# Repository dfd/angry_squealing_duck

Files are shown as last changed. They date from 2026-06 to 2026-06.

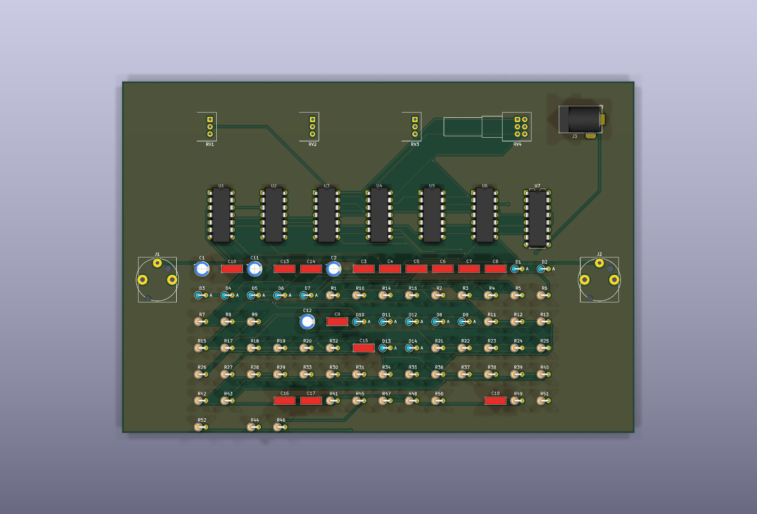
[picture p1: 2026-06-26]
kicad/duck_3d_top.png

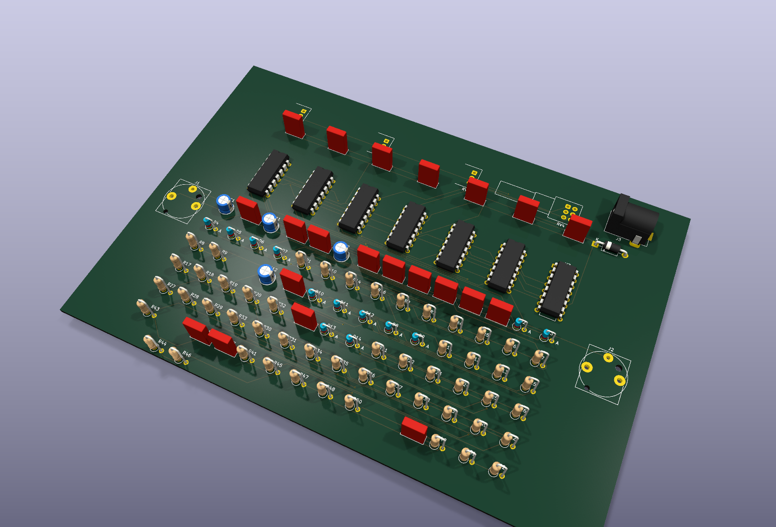
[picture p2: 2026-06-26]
kicad/duck_3d_persp.png

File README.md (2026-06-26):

# Angry Squealing Duck

A guitar pedal: a thick octave-fuzz feeding a dynamics-driven envelope band-pass
("Q-Tron") filter. Designed and voiced entirely in **ngspice**, validated against
real-part models, ready for KiCad.

**Controls (4 knobs + 2 footswitches):**
- **Volume** — output level
- **Anger** — fuzz amount / sustain (Big-Muff-style)
- **Squeal** — up-octave level: CCW = none, ~noon = "ring on top", CW = octave-dominant blast
- **Quack** — envelope band-pass intensity (ganged sweep depth + resonance Q)
- **Master** true-bypass footswitch, and a dedicated **Squeal (octave) footswitch**
  (kick the octave in/out, Hoof-Reaper style)

All knobs CCW = that effect off.

## Signal architecture

```
 IN ─► Input buffer ─► SPLIT ─┬─ AUDIO: Fuzz(Anger) ─┬─► BP envelope filter(Quack) ──┐
                              │                       └─► Octave-up(Squeal) ─► fixed HP┤─►[Volume]─► OUT
                              └─ CONTROL: Envelope follower (raw) ─► Iabc (cutoff) ─────┘
```

Key voicing decisions (each one earned the hard way — see `git log` / memory):
- **Octave AFTER the fuzz** (Octavia / Fender-Blender pattern): rectifying the distorted
  signal yields a prominent ring. Octave *before* the fuzz buried it ~30 dB under the
  fuzz's odd harmonics.
- **Body and octave on separate filter paths** ("hybrid" route): the fuzz body goes
  through the **band-pass** envelope filter (it quacks); the octave goes through a
  **fixed high-pass** (stays clear/bright instead of being swept under). A single shared
  filter ("mixed") muffled the octave.
- **Envelope tapped from the RAW split** (pre-fuzz) so the filter tracks picking dynamics
  — fuzz compresses dynamics away.

## Design choices

- Single **9 V** supply, **op-amp-buffered 4.5 V** virtual ground (`vref`) — a passive
  divider sags under the high-gain fuzz. Every stage input is AC-coupled.
- **Fuzz** = 3-stage cascaded **Big-Muff-style soft-clipper** with asymmetric stages for
  warmth (`fuzz_muff.cir`, default). A single-stage hard clipper (`fuzz.cir`, DOD-250
  family) is kept selectable via the `muff` param.
- **Octave** = op-amp **precision full-wave rectifier** (`fwr.cir`), no transformer.
  `octave_gen.cir` produces octave-only; Squeal level is **quadratic** so noon = ring,
  full = blast (`goct=8`, ~+9 dB octave-over-body, calibrated on real DI clips).
- **Envelope follower** = precision rectifier + **2-pole averaging** (not peak-detect,
  which hunted in a ~12 Hz limit cycle that re-triggered the filter on held notes).
- **Filter** = **LM13700 OTA state-variable** filter (`vcf.cir` behavioral / `vcf_real.cir`
  real). Has LP/BP/HP/mixed taps (Q-Tron-style mode); the hybrid route uses BP for the
  body. Quack maps to a **linear Q (0.7→3.5)** and an envelope-swept cutoff (gm = Iabc).
  gm control is ground-referenced to avoid a virtual-ground latch.
- **Behavioral-ideal first** to lock topology/voicing, then **real part models** for build
  accuracy (`opamp_real.sub` = TL072, `lm13700.sub` = OTA) — validated: voicing essentially
  unchanged on real silicon. See `memory` / `real-parts-and-build-notes`.

## Status

Design, voicing, real-part validation, **and a routed KiCad PCB are complete.**

| done | |
|---|---|
| ✅ | All blocks designed + integrated (input buffer → fuzz → octave → filter → volume) |
| ✅ | Voiced by ear on real guitar (MOTU M2), grid of Squeal×Anger×Quack rendered |
| ✅ | Real part models (TL072 + LM13700) — chain converges, voicing holds |
| ✅ | All-real buildable netlist (`pedal_build.cir`, no B-sources) — re-validated |
| ✅ | Quack sweep restored: V-to-I gain ×73 → body cutoff ~280 Hz→2.1 kHz, auditioned-good |
| ✅ | KiCad PCB: placed, auto-routed, gerbers exported |
| ✅ | **Tier-1 de-risk audit** (`kicad/AUDIT.md`): caught + fixed **10 reversed diodes**; added per-IC decoupling + Schottky protection + center-neg polarity; **DRC 0 unconnected / 0 violations** |

**Quack note:** the real envelope is tiny (~0.04 V peak), so the V-to-I needs high gain
(`Rdi`/`Rdj` = 1.5k, `Rdf`/`Rdk` = 110k → ×73) for the filter to sweep. Quack is most
audible at lower Squeal — at full Squeal the octave sits on top by design.

**Audit caught a board-killer:** `duck.py` (hand-translated) had 10/14 diodes reversed
(fuzz clippers + both rectifiers) — ERC + sim pass anyway since the SPICE is a separate,
correct source. Fixed to match SPICE; see `kicad/AUDIT.md`. **Not yet hardware-validated:**
real noise floor + the LM13700 filter's behavior (the `/50` attenuation hack, Iabc ceiling) —
confirm by breadboarding the filter + fuzz before fab (`kicad/breadboard/`).

## Layout

- `spice/lib/`    — models: `opamp.sub` (ideal), `opamp_real.sub` (TL072),
  `lm13700.sub` (OTA), `diode.mod` (1N4148), `supply.cir` (buffered vref)
- `spice/blocks/` — one `.subckt` per block: `input_buffer`, `fuzz`, `fuzz_muff`, `fwr`,
  `octave_rect`/`octave_gen`, `hpf`, `gmint`+`vcf`/`vcf_real`, `envfollow`,
  `duck`(mixed)/`duck_split`(hybrid/parallel), `pedal`
- `spice/tests/`  — per-block test benches
- `sim/`          — Python harness: `run.py`, `render.py`, `octave_balance.py`,
  `fft_report.py`, `spicelib.py`, `extract_sample.py`
- `audio/in/`     — committed DI samples; `audio/out/` — rendered WAVs (git-ignored)
- `raw_wavs/`     — large source recordings (git-ignored)
- `kicad/`        — the board, generated programmatically:
  - `duck.py` (SKiDL netlist generator) → `duck.net` (ERC-clean) + `BOM.md`
  - `build_pcb.py` (pcbnew: parse netlist → place → board) ; `finish_pcb.py` (values + GND pour)
  - `duck.kicad_pcb` (routed, DRC-clean) ; `gerbers/` + `duck.drl` + `duck-pos.csv` (fab-ready)
  - `duck_3d_top.png` / `duck_3d_persp.png` (3D renders; or open the `.kicad_pcb` in pcbnew → `Alt+3`)
  - `AUDIT.md` (netlist-translation audit + gap fixes) ; `BOM.md` ; `COST.md` (build-cost estimate)
  - `pedal_build.cir` in `spice/blocks/` is the all-real buildable schematic-of-record
- `kicad/breadboard/` — prototype-first docs (build it on a breadboard before the PCB):
  - `BUILD_GUIDE.md` (staged bring-up) + `CONNECTIONS.md` (per-stage wiring tables, net = row)
  - `gen_blocks.py` / `make_tables.py` (generators) ; `0*.png` drawn schematics (simple stages)
- `audio/out/build_grid/` + `build_grid_orig/` — full real-parts grids (Squeal×Anger×Quack ∈ {0,0.5,1})

## KiCad / PCB workflow

The board is generated entirely by script (no GUI), bridging two Pythons because
`pcbnew` is built for system Python 3.14 while the sim harness uses uv's 3.13:
```
# 1. netlist (uv / 3.13)
KICAD8_SYMBOL_DIR=/usr/share/kicad/symbols uv run kicad/duck.py     # -> duck.net (+ ERC)
# 2. place + board (system python 3.14, needs pcbnew)
/usr/bin/python3 kicad/build_pcb.py                                 # -> duck.kicad_pcb
# 3. route: export DSN, run freerouting (needs a display, e.g. :0), import SES
/usr/bin/python3 -c "import pcbnew,sys; b=pcbnew.LoadBoard('kicad/duck.kicad_pcb'); pcbnew.ExportSpecctraDSN(b,'/tmp/duck.dsn')"
DISPLAY=:0 java -jar freerouting.jar -de /tmp/duck.dsn -do /tmp/duck.ses -mp 14
/usr/bin/python3 -c "import pcbnew; b=pcbnew.LoadBoard('kicad/duck.kicad_pcb'); pcbnew.ImportSpecctraSES(b,'/tmp/duck.ses'); pcbnew.SaveBoard('kicad/duck.kicad_pcb',b)"
# 4. finishing pass (snap values + GND pour) + checks + fab outputs
/usr/bin/python3 kicad/finish_pcb.py
kicad-cli pcb drc kicad/duck.kicad_pcb
kicad-cli pcb export gerbers --output kicad/gerbers/ kicad/duck.kicad_pcb
```
Board: 2-layer, 175×120 mm (1590DD-class), 6× TL074 + 1× LM13700 + 14× 1N4148,
4 knobs (Volume / Anger / Squeal / Quack-dual-gang). No graphical schematic
(eeschema has no scripting API) — `pedal_build.cir` + `duck.py` are the design-of-record.

## Prototype it first (breadboard)

`kicad/breadboard/` holds **prototype-first** docs. Build + test the circuit on solderless
breadboards one stage at a time before committing to the PCB — see `BUILD_GUIDE.md` for the
staged bring-up order (supply → input → fuzz → octave → envelope → V-to-I → filter → output)
and `CONNECTIONS.md` for per-stage wiring tables (**each net = one breadboard row**; IC pins
annotated). Each stage uses its own op-amp IC (not the PCB's shared packing) so it tests
standalone. Regenerate with `gen_blocks.py` + `make_tables.py`. (SKiDL's schematic auto-router
only handles the simple stages, so the dense ones are table-only — better for breadboarding anyway.)

## Workflow

Run a block test bench:
```
uv run sim/run.py spice/tests/tb_input_buffer.cir
```
Render guitar through the pedal (→ `audio/out/`):
```
# the LOCKED, buildable design (= the PCB): real parts, no B-sources, V-to-I gain x73
uv run sim/render.py [wav] --build --squeal 1 --anger 0.8 --quack 0.6 [--subdir name]
# the behavioral routes (faster iteration / experiments):
uv run sim/render.py [wav] --route hybrid --squeal 1 --anger 0.8 --quack 0.6 [--real]
```
- **`--build`** = `pedal_build.cir`, the all-real buildable pedal that matches the PCB (use this).
- `--real` = TL072 + LM13700 models on the behavioral chain · `--route` = mixed|hybrid|parallel
- Scratch files are unique per render, so render a grid in parallel on many cores:
  `... | xargs -P 24 -I A sh -c 'uv run sim/render.py A'`
  (the committed `audio/out/build_grid/` + `build_grid_orig/` are the `--build` grids of
  Squeal×Anger×Quack ∈ {0, 0.5, 1.0} on both DI samples).

Measure octave-vs-body level on real clips (don't trust single-note benches — they
over-read the octave ~6 dB):
```
uv run sim/octave_balance.py --wav audio/in/di_sample.wav --squeal 1.0 --goct 8
```

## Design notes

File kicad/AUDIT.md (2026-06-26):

# Netlist audit + gap-fixes (Tier-1 de-risk)

Virtual pass before breadboarding/fab: cross-checked the hand-written `duck.py` netlist
against the validated SPICE (`spice/blocks/*`) + part datasheets, and closed the physical gaps
the simulation can't model. ERC only proves the copper matches `duck.py` — it can't catch a
wrong translation, so this was done by hand.

## 🔴 Bug found + fixed — 10 of 14 diodes were reversed

The biggest risk in any hand-translated netlist: diode orientation. ERC and simulation both
pass regardless (the SPICE blocks are a *separate*, correct source). Found:

| where | count | was | now |
|---|---|---|---|
| Fuzz clipper `dba`/`dbb` (the 2-diode side of each asymmetric soft-clipper), ×3 stages | 6 | reversed | matches `fuzz_muff.cir` (`Da1`/`Db1a`/`Db1b`) |
| Precision rectifier `d1`/`d2`, ×2 instances (octave + envelope) | 4 | reversed (even contradicted their own comments) | matches `fwr.cir` (`D1 a1o n1`, `D2 hw a1o`) |

`1N4148` symbol pinout is **pin 1 = K (cathode), pin 2 = A (anode)** — verified from the
library, not assumed. **Built as-was, this board would have had a broken octave + envelope
(no quack) and a wrong-sounding fuzz.** This alone justified the audit.

## ✅ Verified correct (no change needed)

- **TL074** section pinout — out/−/+ = (1,2,3)(7,6,5)(8,9,10)(14,13,12), V+ 4 / V− 11.
- **LM13700** — Iabc 1/16, +in 3/14, −in 4/13, out 5/12, V+ 11 / V− 6; non-inverting
  integrators match `vcf_build.cir`.
- All op-amp stage wiring (input buffer, 3 fuzz gain stages, both rectifiers, envelope,
  octave makeup, V-to-I diff amp ×73, SVF summer/inverter, output summer + buffers).
- **Pots** — Volume/Squeal (dividers), Anger (rheostat), **Quack dual-gang**
  (`R_Potentiometer_Dual_Separate`: 1-3 = sweep crossfade, 4-6 = filter-Q). All correct.
- **Jacks** (AudioJack2 T/S, Barrel_Jack), the Vref buffer + divider, and the unused
  LM13700 buffer/diode-bias pins (tied/NC).

## 🟢 Physical gaps closed

1. **Per-IC decoupling** — added **7× 0.1 µF** from V+ → GND, one at each IC, **placed
   beside the chip** on the board. Was missing entirely (only a 100 µF bulk + 47 µF Vref cap
   existed) — a real oscillation/noise risk on a high-gain 7-IC design that SPICE can't show.
2. **Reverse-protection diode** — 1N4148 → **1N5817 Schottky** (handles supply current, low
   drop), placed by the DC jack.
3. **DC polarity pinned to center-negative** (Boss/standard: center pin = GND, sleeve = +9 V).
   ⚠️ **Verify against your barrel jack's actual pinout** — the Schottky blocks damage if a
   reversed/center-positive supply is plugged in, but get the convention right for it to power on.

## Breadboard generator independently verified (second translation)

The breadboard docs (`kicad/breadboard/CONNECTIONS.md`, schematics) come from a *separate*
hand-written generator — `kicad/breadboard/gen_blocks.py` — not `duck.py`. It was audited
against the SPICE on its own:

- **All 14 diodes correct.** gen_blocks uses a clean `diode(part, anode, cathode)` helper
  (`part[2]=A, part[1]=K`); the fuzz clippers (`Da1/Db1a/Db1b`) and both rectifiers
  (`D1 a1o n1`, `D2 hw a1o`) match the SPICE in `CONNECTIONS.md`. **The `duck.py` diode bug
  did NOT exist here** — it was specific to duck.py's direct K/A pin assignment.
- TL072/TL074 section maps + power pins, the **LM13700** pinout (Iabc 1/16, +in 3/14, −in 4/13,
  out 5/12, V+ 11 / V− 6), and key values (V-to-I ×73, octave makeup, filter attenuator) all
  match the design.

So the audit covers **both** outputs: the PCB netlist (`duck.py`, diodes fixed) and the
breadboard docs (`gen_blocks.py`, already correct). No breadboard changes needed.

## Still untested by simulation (real-silicon, for the breadboard to confirm)
- Noise floor and real oscillation behavior (no noise analysis exists; layout-dependent).
- The LM13700 filter with the **/50 input attenuation** hack instead of the on-chip
  linearizing diodes (diode-bias pins left open) — distortion/headroom, and behavior near the
  ~1 mA Iabc ceiling at full sweep. These are exactly what the Tier-2 breadboard checks.

Bottom line: the **logic/translation bugs are now scrubbed out** (diodes) and the **known
physical gaps closed** (decoupling, power). What remains is genuine real-silicon behavior —
the stuff worth breadboarding the filter + fuzz for.

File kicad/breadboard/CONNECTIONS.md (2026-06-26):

# Angry Squealing Duck - breadboard connection tables

Each **net = one breadboard row**: put every listed pin in that row. IC pins are
annotated with their function. Build in numbered order (see BUILD_GUIDE.md).

## supply - Supply / 4.5 V Vref

**ICs:** U1 (TL072)  |  **Pots:** none

| net (breadboard row) | connect these pins |
|---|---|
| **GND** | C1.2, C2.2, R2.2, U1.4 (V- (GND)) |
| **NREF** | C2.1, R1.2, R2.1, U1.3 (IN1+) |
| **V9** | D1.2 (A) |
| **VCC** | C1.1, D1.1 (K (band)), R1.1, U1.8 (V+ (VCC)) |
| **VREF** | U1.1 (OUT1), U1.2 (IN1-) |

## input_buffer - Input buffer

**ICs:** U1 (TL072)  |  **Pots:** none

| net (breadboard row) | connect these pins |
|---|---|
| **GND** | U1.4 (V- (GND)) |
| **IN** | C1.1 |
| **NP** | C1.2, R1.1, U1.3 (IN1+) |
| **SIG** | U1.1 (OUT1), U1.2 (IN1-) |
| **VCC** | U1.8 (V+ (VCC)) |
| **VREF** | R1.2 |

## fuzz_anger - Fuzz (Anger) - 3-stage Muff

**ICs:** U1 (TL074)  |  **Pots:** RV1 (100k)

| net (breadboard row) | connect these pins |
|---|---|
| **FZ** | C7.1, R10.2 |
| **FZ1** | C2.2, C3.1, D1.1 (K (band)), D2.2 (A), R3.2, U1.1 (OUT1) |
| **FZ2** | C4.2, C5.1, D4.1 (K (band)), D5.2 (A), R6.2, U1.7 (OUT2) |
| **FZ3** | C6.2, D7.1 (K (band)), D8.2 (A), R10.1, R9.2, U1.8 (OUT3) |
| **GND** | U1.11 (V- (GND)) |
| **N$1** | C1.2, R1.1, R2.1 |
| **N$10** | C5.2, R7.1, R8.1 |
| **N$11** | C6.1, D7.2 (A), D9.1 (K (band)), R8.2, R9.1, U1.9 (IN3-) |
| **N$13** | D8.1 (K (band)), D9.2 (A) |
| **N$2** | R2.2, RV1.1 |
| **N$3** | C2.1, D1.2 (A), D3.1 (K (band)), R3.1, RV1.2, RV1.3, U1.2 (IN1-) |
| **N$5** | D2.1 (K (band)), D3.2 (A) |
| **N$6** | C3.2, R4.1, R5.1 |
| **N$7** | C4.1, D4.2 (A), D6.1 (K (band)), R5.2, R6.1, U1.6 (IN2-) |
| **N$9** | D5.1 (K (band)), D6.2 (A) |
| **SIG** | C1.1 |
| **VCC** | U1.4 (V+ (VCC)) |
| **VREF** | C7.2, R1.2, R4.2, R7.2, U1.10 (IN3+), U1.3 (IN1+), U1.5 (IN2+) |

## octave_squeal - Octave (Squeal)

**ICs:** U1 (TL074)  |  **Pots:** RV1 (100k)

| net (breadboard row) | connect these pins |
|---|---|
| **FZ** | C1.1 |
| **GND** | U1.11 (V- (GND)) |
| **N$1** | C1.2, R1.1, R3.1 |
| **N$10** | R8.2, R9.1, U1.9 (IN3-) |
| **N$11** | C4.1, RV1.2 |
| **N$12** | C4.2, R10.1, U1.12 (IN4+) |
| **N$2** | R5.2, R6.1, U1.7 (OUT2) |
| **N$3** | D1.1 (K (band)), R1.2, R2.1, U1.2 (IN1-) |
| **N$4** | R3.2, R4.2, R5.1, U1.6 (IN2-) |
| **N$5** | D2.2 (A), R2.2, R4.1 |
| **N$6** | D1.2 (A), D2.1 (K (band)), U1.1 (OUT1) |
| **N$7** | C2.1, C3.1, R6.2 |
| **N$8** | C3.2, R7.1, U1.10 (IN3+) |
| **N$9** | R8.1, RV1.1, U1.8 (OUT3) |
| **OCTF** | U1.13 (IN4-), U1.14 (OUT4) |
| **VCC** | U1.4 (V+ (VCC)) |
| **VREF** | C2.2, R10.2, R7.2, R9.2, RV1.3, U1.3 (IN1+), U1.5 (IN2+) |

## envelope - Envelope follower

**ICs:** U1 (TL074)  |  **Pots:** none

| net (breadboard row) | connect these pins |
|---|---|
| **CV** | U1.8 (OUT3), U1.9 (IN3-) |
| **GND** | U1.11 (V- (GND)) |
| **N$1** | R5.2, R6.1, U1.7 (OUT2) |
| **N$2** | D1.1 (K (band)), R1.2, R2.1, U1.2 (IN1-) |
| **N$3** | R3.2, R4.2, R5.1, U1.6 (IN2-) |
| **N$4** | D2.2 (A), R2.2, R4.1 |
| **N$5** | D1.2 (A), D2.1 (K (band)), U1.1 (OUT1) |
| **N$6** | C1.1, R6.2, R7.1 |
| **N$7** | C2.1, R7.2, U1.10 (IN3+) |
| **SIG** | R1.1, R3.1 |
| **VCC** | U1.4 (V+ (VCC)) |
| **VREF** | C1.2, C2.2, U1.3 (IN1+), U1.5 (IN2+) |

## quack_vtoi - Quack control (envelope -> V-to-I)

**ICs:** U1 (TL074)  |  **Pots:** RV1 (100k)

| net (breadboard row) | connect these pins |
|---|---|
| **CV** | R5.1 |
| **ECTL** | R4.2, RV1.3, U1.7 (OUT2) |
| **GND** | R2.2, U1.11 (V- (GND)) |
| **N$1** | R1.2, R2.1, U1.3 (IN1+) |
| **N$2** | R3.2, R4.1, U1.6 (IN2-) |
| **N$3** | R5.2, R6.1, U1.5 (IN2+) |
| **N$4** | RV1.2, U1.10 (IN3+) |
| **VBIAS** | U1.8 (OUT3), U1.9 (IN3-) |
| **VCC** | R1.1, U1.4 (V+ (VCC)) |
| **VOFF** | R6.2, RV1.1, U1.1 (OUT1), U1.2 (IN1-) |
| **VREF** | R3.1 |

## filter_lm13700 - LM13700 band-pass filter

**ICs:** U1 (TL074), U2 (TL072), U3 (LM13700)  |  **Pots:** RV1 (100k)

| net (breadboard row) | connect these pins |
|---|---|
| **BODYF** | U2.1 (OUT1), U2.2 (IN1-) |
| **BP** | R12.1, R8.1, U1.8 (OUT3), U1.9 (IN3-), U2.3 (IN1+) |
| **FZ** | R3.1 |
| **GND** | U1.11 (V- (GND)), U2.4 (V- (GND)), U3.6 (V-) |
| **HP** | R10.1, R7.2, U1.7 (OUT2) |
| **LP** | R6.1, U1.13 (IN4-), U1.14 (OUT4) |
| **N$1** | R5.2, R6.2, R7.1, R9.2, RV1.2, RV1.3, U1.6 (IN2-) |
| **N$10** | C1.1, U1.10 (IN3+), U3.5 (OUT-A) |
| **N$11** | R12.2, R13.1, U3.14 (IN+B) |
| **N$12** | C2.1, U1.12 (IN4+), U3.12 (OUT-B) |
| **N$4** | R1.2, U3.1 (Iabc-A) |
| **N$5** | R2.2, U3.16 (Iabc-B) |
| **N$6** | R3.2, R4.1, U1.2 (IN1-) |
| **N$7** | R4.2, R5.1, U1.1 (OUT1) |
| **N$8** | R8.2, R9.1, RV1.1 |
| **N$9** | R10.2, R11.1, U3.3 (IN+A) |
| **VBIAS** | R1.1, R2.1 |
| **VCC** | U1.4 (V+ (VCC)), U2.8 (V+ (VCC)), U3.11 (V+) |
| **VREF** | C1.2, C2.2, R11.2, R13.2, U1.3 (IN1+), U1.5 (IN2+), U3.13 (IN-B), U3.4 (IN-A) |

## output - Output (mix + Volume)

**ICs:** U1 (TL072)  |  **Pots:** RV1 Volume (100k, audio taper)

| net (breadboard row) | connect these pins |
|---|---|
| **BODYF** | R1.1  (from filter stage BODYF) |
| **OCTF** | R2.1  (from octave stage OCTF) |
| **NSUM** | R1.2, R2.2, R3.1, U1.2 (IN1-) |
| **OPRE** | R3.2, U1.1 (OUT1), RV1.1 (end) |
| **VW** | RV1.2 (wiper), U1.5 (IN2+) |
| **OUT** | U1.7 (OUT2), U1.6 (IN2-)  -> output jack tip |
| **VREF** | U1.3 (IN1+), RV1.3 (end) |
| **VCC** | U1.8 (V+) |
| **GND** | U1.4 (V-) |

_R1=R2=R3 = 22k (mixer). Body + octave sum here, then Volume sets output level._

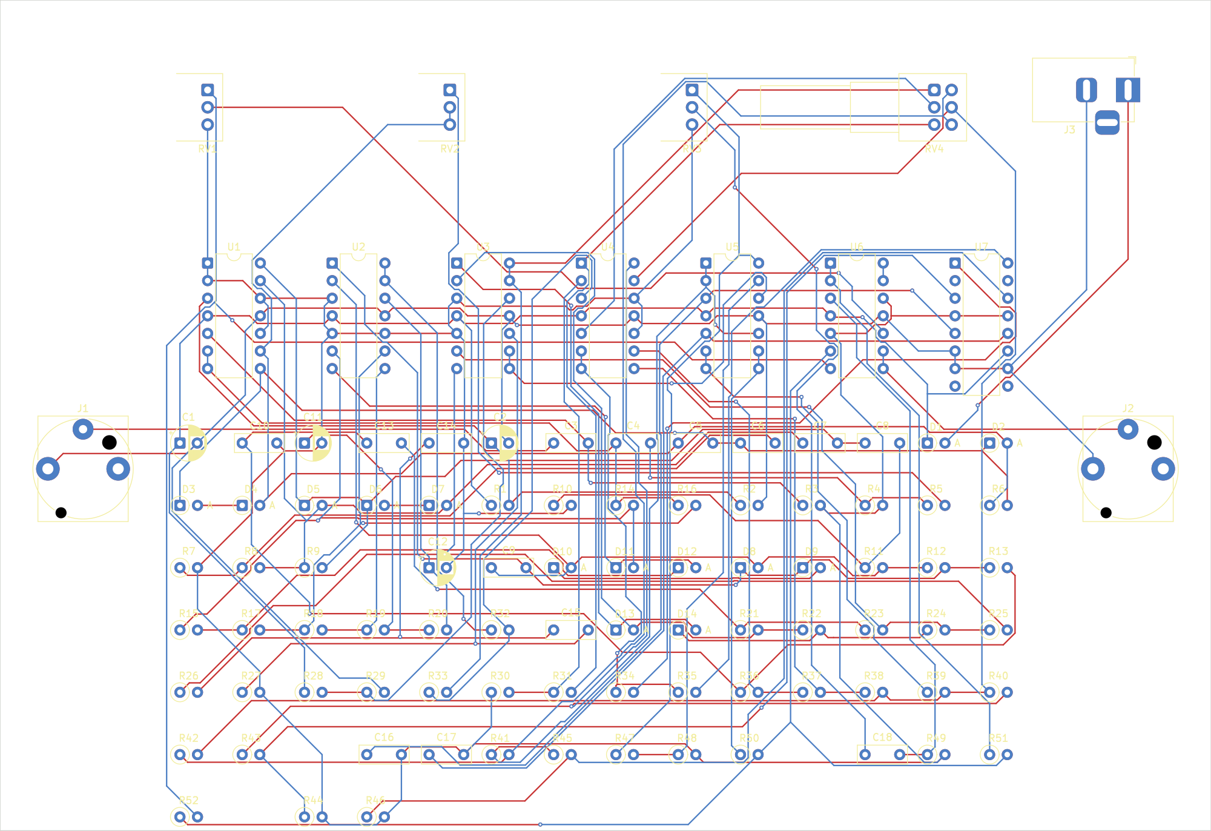
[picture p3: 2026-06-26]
kicad/duck_routed.png

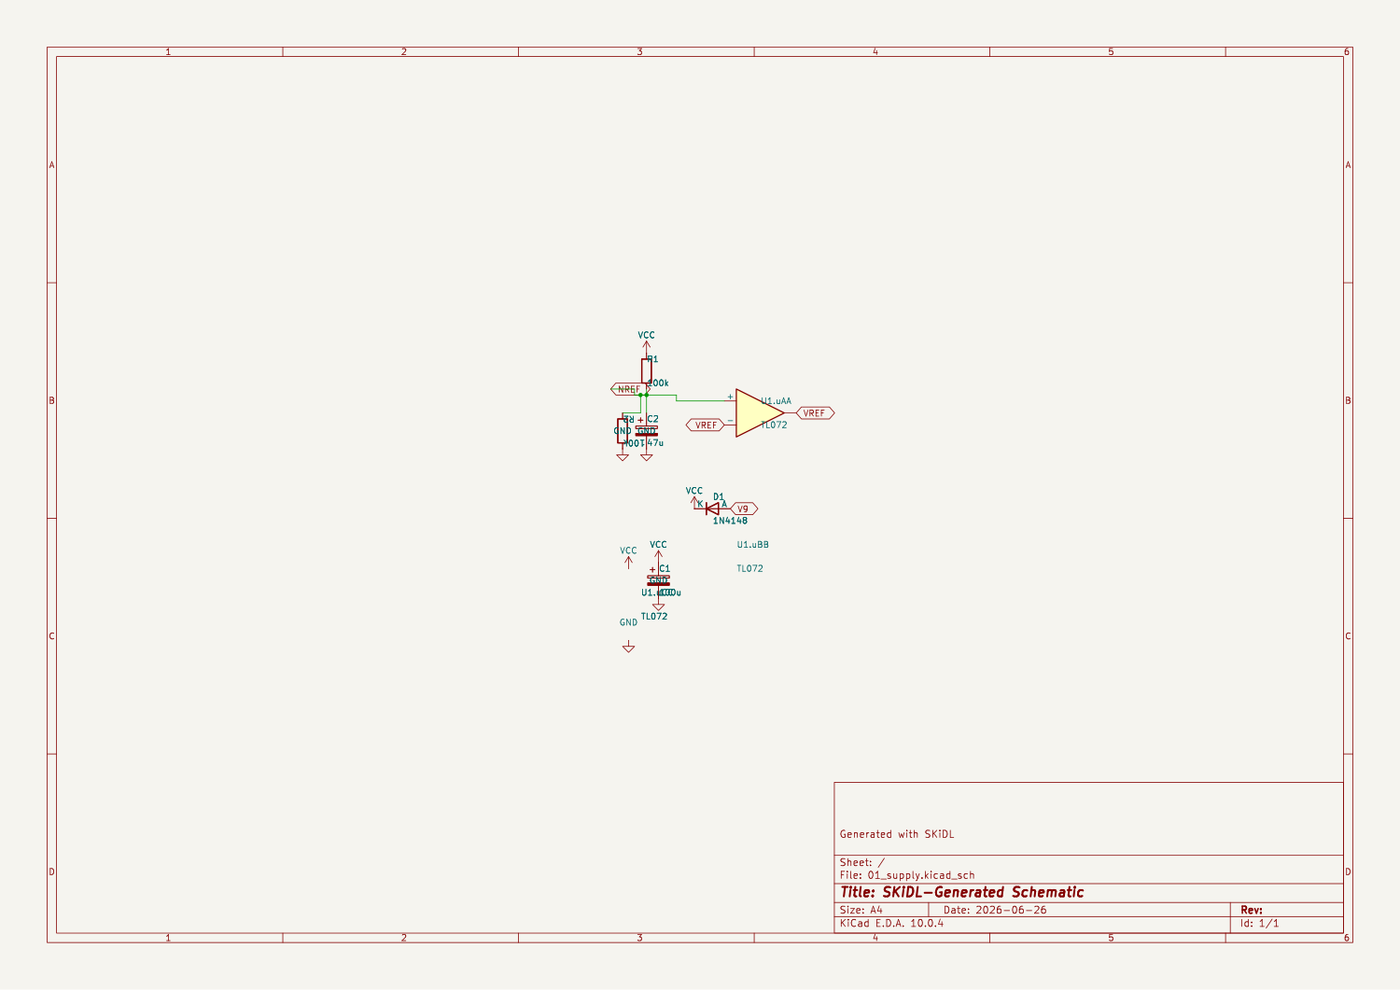
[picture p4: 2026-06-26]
kicad/breadboard/01_supply.png

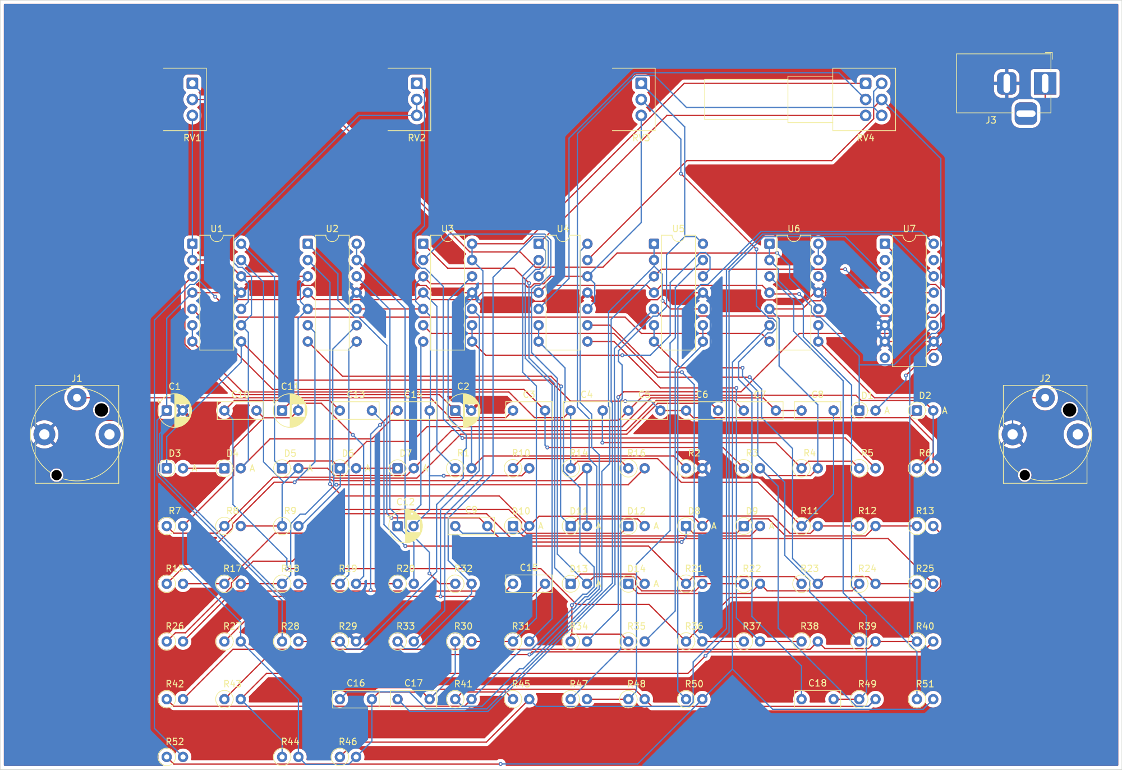
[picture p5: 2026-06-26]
kicad/duck_final.png

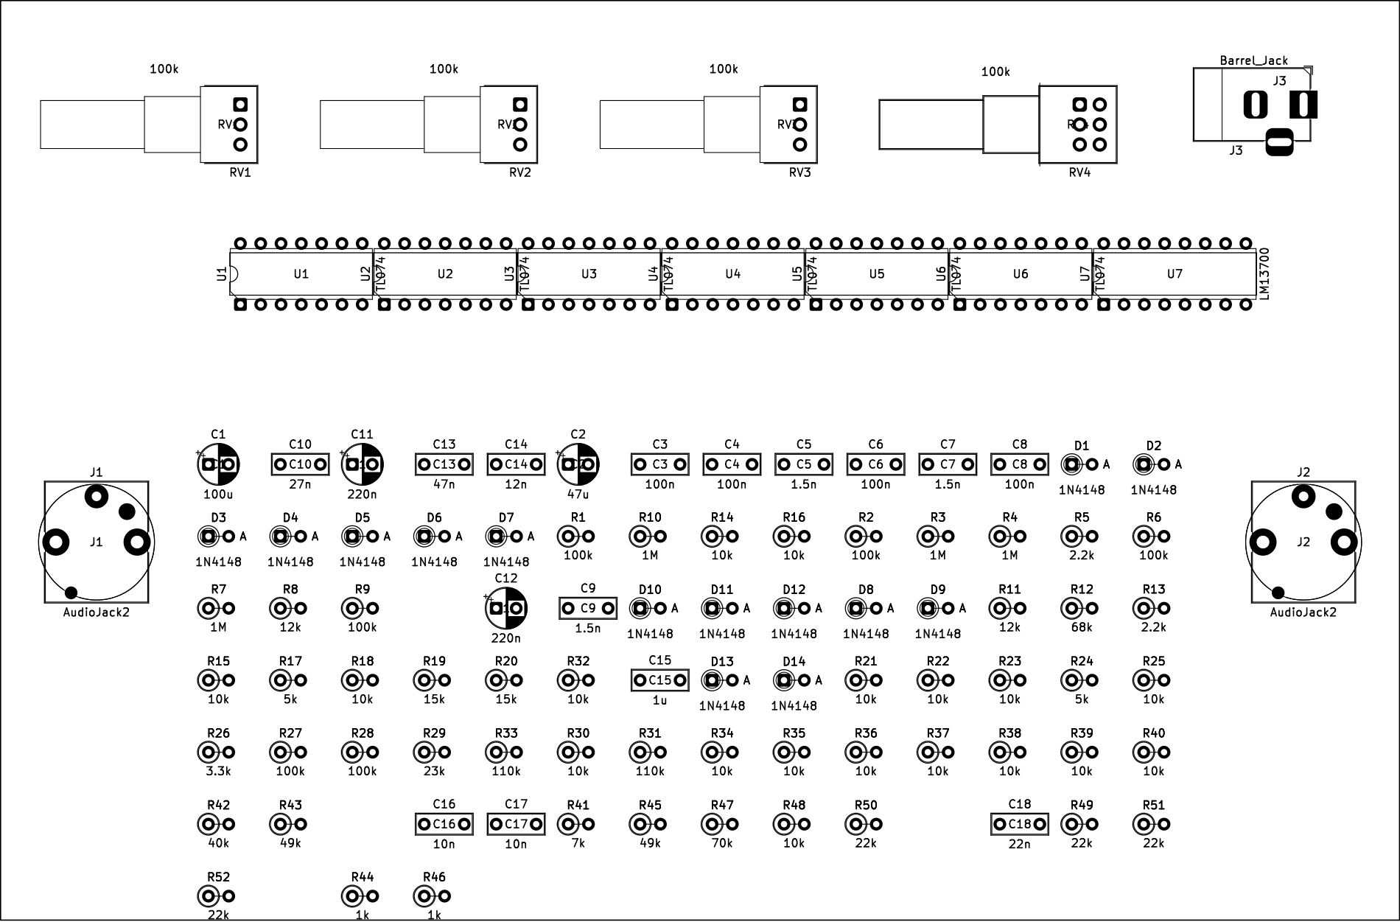
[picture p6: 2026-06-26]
kicad/duck_top.png

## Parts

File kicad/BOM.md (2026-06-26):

# Angry Squealing Duck - BOM (from kicad/duck.net)

## ICs (7)
- 6x TL074: U1, U2, U3, U4, U5, U6
- 1x LM13700: U7

## Potentiometers (4)
- 4x 100k: RV1, RV2, RV3, RV4

## Diodes (14)
- 13x 1N4148: D2, D3, D4, D5, D6, D7, D8, D9, D10, D11, D12, D13, D14
- 1x 1N5817: D1

## Resistors (52)
- 16x 10k: R14, R15, R16, R18, R21, R22, R23, R25, R34, R35, R36, R37, R38, R39, R40, R48
- 6x 100k: R1, R2, R6, R9, R27, R28
- 5x 22k: R29, R49, R50, R51, R52
- 4x 1M: R3, R4, R7, R10
- 2x 12k: R8, R11
- 2x 68k: R12, R47
- 2x 2.2k: R5, R13
- 2x 4.7k: R17, R24
- 2x 15k: R19, R20
- 2x 1.5k: R30, R32
- 2x 110k: R31, R33
- 2x 47k: R43, R45
- 2x 1k: R44, R46
- 1x 3.3k: R26
- 1x 6.8k: R41
- 1x 39k: R42

## Capacitors (25)
- 11x 100n: C3, C4, C6, C8, C19, C20, C21, C22, C23, C24, C25
- 3x 1.5n: C5, C7, C9
- 2x 220n: C11, C12
- 2x 10n: C16, C17
- 1x 100u: C1
- 1x 27n: C10
- 1x 47n: C13
- 1x 12n: C14
- 1x 1u: C15
- 1x 22n: C18
- 1x 47u: C2

## Connectors (3)
- 2x AudioJack2: J1, J2
- 1x Barrel_Jack: J3

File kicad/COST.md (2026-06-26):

# Angry Squealing Duck — build cost estimate

Rough estimates from `BOM.md`, **budget DIY sourcing** (Tayda / AliExpress). Mouser/DigiKey
run ~1.5–2× higher. USD, one unit. These are ballpark figures, **not live quotes**. The board
is large (175×120 mm), so fab + enclosure cost more than a typical compact pedal.

Parts in the BOM: 6× TL074 + 1× LM13700, 4× 100k pots (RV4 = dual-gang Quack), 14× 1N4148,
52 resistors, 18 caps. Build extras (not in BOM): 2× 3PDT footswitches (true-bypass + Squeal),
LEDs, knobs, IC sockets, enclosure.

## 🍞 Breadboard (prototype)

| item | est. |
|---|---|
| 3–4 full-size breadboards *(reusable)* | $20–30 |
| jumper wire kit *(reusable)* | $8–15 |
| 9 V supply (battery+clip or adapter) | $3–8 |
| ~8 TL07x op-amps + 1 LM13700 | $7–10 |
| 14× 1N4148 | ~$0.50 |
| ~55 resistors + 18 caps *(or assortment kits, reusable)* | $6–10 |
| 4 pots (3 single + 1 dual-gang 100k) | $8–14 |
| *no jacks / enclosure / footswitches needed* | — |
| **Total, buying fresh** | **≈ $55–85** |
| **Marginal** (if you already own breadboards/jumpers/supply/kits) | **≈ $25–40** |

Not giggable — it's a test rig. But it's the cheapest way to confirm the circuit before
committing to copper. See `BUILD_GUIDE.md` for the staged bring-up.

## 🟢 PCB (finished, giggable pedal)

| item | est. |
|---|---|
| PCB fab — 175×120 mm 2-layer, **5 pcs** + shipping (you keep 5 boards) | $35–55 |
| 6× TL074 + 1× LM13700 | $5–7 |
| 7× IC sockets | ~$2 |
| 14× 1N4148 | ~$0.50 |
| 52 resistors + 18 caps | $5–8 |
| 4 pots + 4 knobs | $11–20 |
| 2× ¼" jacks + DC jack | $4–7 |
| 2× 3PDT footswitches + 2 LEDs | $6–10 |
| enclosure (1590DD-class) | $12–18 |
| wire / solder / battery snap / standoffs | ~$5 |
| **First complete pedal** (incl the 5-board fab batch) | **≈ $85–130** |
| **Each additional build** (from the 4 spare boards) | **≈ $50–75** |

## Takeaways

- **Electronics are cheap (~$15–20).** The cost is the *mechanical* stuff — enclosure,
  footswitches, jacks, knobs — plus the board. The breadboard skips all of it.
- **The 175×120 mm board is the cost driver.** It's past the cheap ≤100×100 mm fab tier *and*
  needs a large (1590DD-class) enclosure. Going SMD or splitting the board would cut both.
- **LM13700** is the priciest / rarest active part (~$2) — order a spare.
- **Shipping** is often the single biggest line on a small order ($5–20+) — batch one cart.
- Budget sources (Tayda + AliExpress) hit the low end; Mouser/DigiKey ~1.5–2×.

**Bottom line:** prototype on breadboard for **~$25–40** (if you have the basics), then the
**first finished pedal is ~$85–130**, dropping to **~$50–75** for builds 2–5 off the same
board batch.

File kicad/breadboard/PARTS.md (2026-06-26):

# Breadboard parts list — Angry Squealing Duck

A clean shopping list for the breadboard build. **Every component here rolls forward into the
PCB build** (pull from the breadboard, socket the ICs, re-solder the passives) — you do NOT buy
the electronics twice. Build + wiring instructions: **`BUILD_GUIDE.md`**; per-stage wiring
tables: **`CONNECTIONS.md`**; cost: **`COST.md`**.

## Reusable lab kit (one-time, not pedal-specific — keep for every project)
- 3–4 full-size (830-point) solderless breadboards
- jumper-wire kit (assorted lengths)
- 9 V supply (battery + clip, or a regulated adapter)
- a multimeter (and a scope/amp to listen, if you have one)
- a few alligator/clip leads (use instead of jacks while testing)

## ICs
Op-amps are spread **one stage per chip** on the breadboard (so each stage tests on its own);
on the PCB they pack into 6× TL074. Buying all TL074 covers both (a TL074 stands in anywhere
a dual would go) — get a couple spares.
| part | qty (incl spares) | notes |
|---|---|---|
| TL074 (quad op-amp, DIP-14) | 7 | the workhorse; PCB uses 6 |
| LM13700 (dual OTA, DIP-16) | 2 | the filter — priciest/rarest part, 1 spare |
| DIP IC sockets (14- and 16-pin) | for the PCB later | socket the LM13700 at least |

## Diodes (14)
| value | qty |
|---|---|
| 1N4148 | 13 |
| 1N5817 | 1 |
- 1N4148 = the fuzz clippers + the two precision rectifiers. 1N5817 = reverse-polarity protection.

## Resistors (52)  — 1/4 W, any tolerance (5% fine)
| value | qty |
|---|---|
| 10k | 16 |
| 100k | 6 |
| 22k | 5 |
| 1M | 4 |
| 12k | 2 |
| 68k | 2 |
| 2.2k | 2 |
| 4.7k | 2 |
| 15k | 2 |
| 1.5k | 2 |
| 110k | 2 |
| 47k | 2 |
| 1k | 2 |
| 3.3k | 1 |
| 6.8k | 1 |
| 39k | 1 |

## Capacitors (25)
| value | qty | type |
|---|---|---|
| 100n | 11 |
| 1.5n | 3 |
| 220n | 2 |
| 10n | 2 |
| 100u | 1 |
| 27n | 1 |
| 47n | 1 |
| 12n | 1 |
| 1u | 1 |
| 22n | 1 |
| 47u | 1 |
- **100 µF, 47 µF, 220 n** → electrolytic.  **1.5 n / 10 n / 12 n / 22 n / 27 n / 47 n / 100 n / 1 µF** → film or ceramic.
- The **7× of the 100 n** are per-IC decoupling (one 0.1 µF at each chip's V+ pin) — don't skip them.

## Pots (4 × 100 kΩ)
| control | part |
|---|---|
| Volume | 100k single (audio/log taper) |
| Anger | 100k single (any taper; reverse-log ideal) |
| Squeal | 100k single (audio/log taper) |
| **Quack** | 100k **dual-gang** (one knob, two ganged sections) — *or* two 100k singles turned together for testing |
- Add 4 knobs when you build the PCB/enclosure.

## NOT needed for the breadboard (buy at PCB time — see COST.md)
PCB, IC sockets, 2× 3PDT footswitches, enclosure, knobs, 1/4" jacks + DC jack.

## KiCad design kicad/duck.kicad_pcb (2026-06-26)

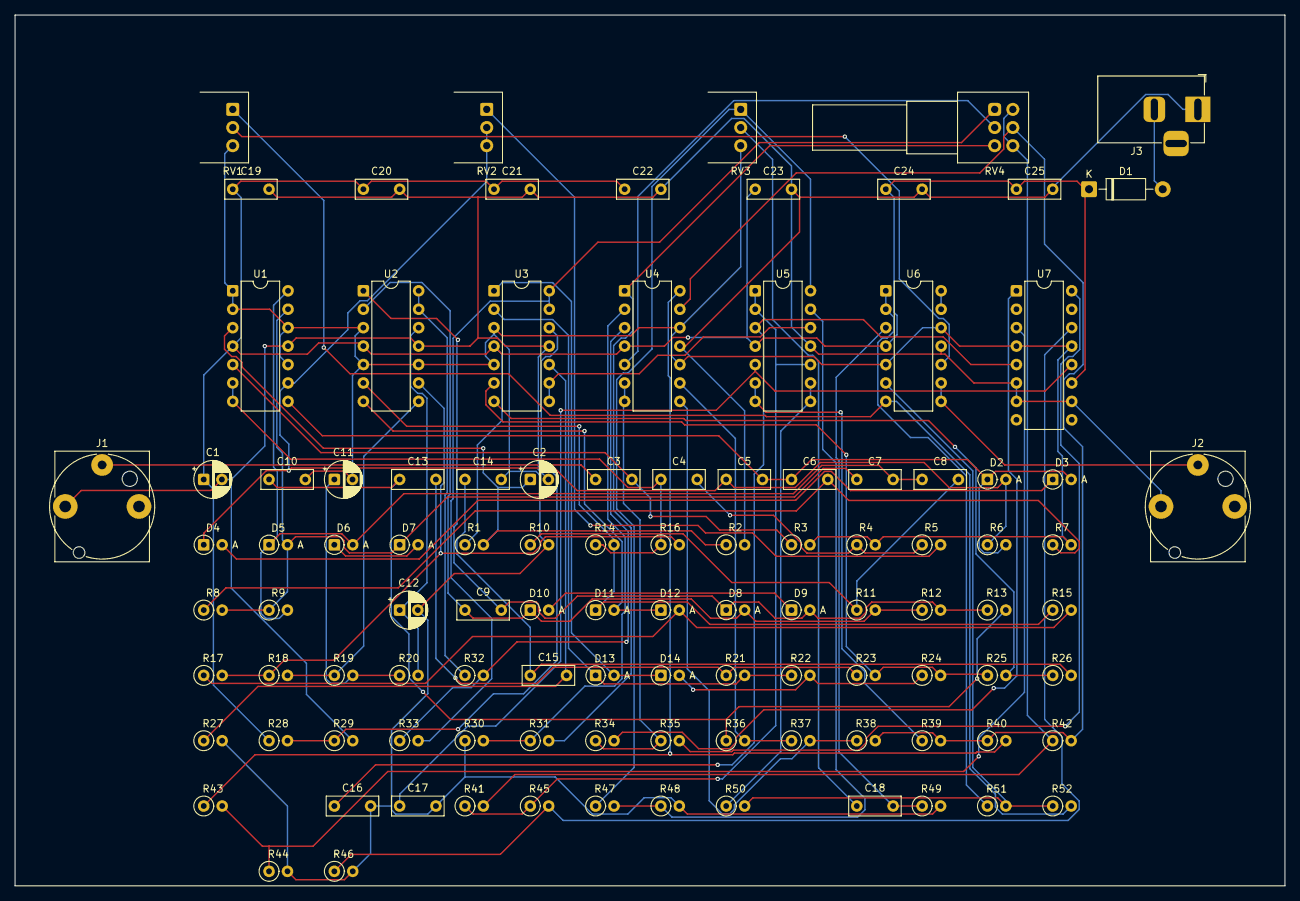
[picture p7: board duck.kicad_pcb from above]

Board: 2 copper layers, 175.0 x 120.0 mm, 105 parts (0 on the bottom side), 70 nets.

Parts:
C1: 100u; CP_Radial_D5.0mm_P2.50mm
C2: 47u; CP_Radial_D5.0mm_P2.50mm
C3, C4, C6, C8, C19, C20, C21, C22, C23, C24, C25: 100n; C_Rect_L7.0mm_W2.5mm_P5.00mm
C5, C7, C9: 1.5n; C_Rect_L7.0mm_W2.5mm_P5.00mm
C10: 27n; C_Rect_L7.0mm_W2.5mm_P5.00mm
C11, C12: 220n; CP_Radial_D5.0mm_P2.50mm
C13: 47n; C_Rect_L7.0mm_W2.5mm_P5.00mm
C14: 12n; C_Rect_L7.0mm_W2.5mm_P5.00mm
C15: 1u; C_Rect_L7.0mm_W2.5mm_P5.00mm
C16, C17: 10n; C_Rect_L7.0mm_W2.5mm_P5.00mm
C18: 22n; C_Rect_L7.0mm_W2.5mm_P5.00mm
D1: 1N5817; D_DO-41_SOD81_P10.16mm_Horizontal
D2, D3, D4, D5, D6, D7, D8, D9, D10, D11, D12, D13, D14: 1N4148; D_DO-35_SOD27_P2.54mm_Vertical_AnodeUp
J1, J2: AudioJack2; Jack_6.35mm_Neutrik_NJ3FD-V_Vertical
J3: Barrel_Jack; BarrelJack_Horizontal
R1, R2, R6, R9, R27, R28: 100k; R_Axial_DIN0207_L6.3mm_D2.5mm_P2.54mm_Vertical
R3, R4, R7, R10: 1M; R_Axial_DIN0207_L6.3mm_D2.5mm_P2.54mm_Vertical
R5, R13: 2.2k; R_Axial_DIN0207_L6.3mm_D2.5mm_P2.54mm_Vertical
R8, R11: 12k; R_Axial_DIN0207_L6.3mm_D2.5mm_P2.54mm_Vertical
R12, R47: 68k; R_Axial_DIN0207_L6.3mm_D2.5mm_P2.54mm_Vertical
R14, R15, R16, R18, R21, R22, R23, R25, R34, R35, R36, R37, R38, R39, R40, R48: 10k; R_Axial_DIN0207_L6.3mm_D2.5mm_P2.54mm_Vertical
R17, R24: 4.7k; R_Axial_DIN0207_L6.3mm_D2.5mm_P2.54mm_Vertical
R19, R20: 15k; R_Axial_DIN0207_L6.3mm_D2.5mm_P2.54mm_Vertical
R26: 3.3k; R_Axial_DIN0207_L6.3mm_D2.5mm_P2.54mm_Vertical
R29, R49, R50, R51, R52: 22k; R_Axial_DIN0207_L6.3mm_D2.5mm_P2.54mm_Vertical
R30, R32: 1.5k; R_Axial_DIN0207_L6.3mm_D2.5mm_P2.54mm_Vertical
R31, R33: 110k; R_Axial_DIN0207_L6.3mm_D2.5mm_P2.54mm_Vertical
R41: 6.8k; R_Axial_DIN0207_L6.3mm_D2.5mm_P2.54mm_Vertical
R42: 39k; R_Axial_DIN0207_L6.3mm_D2.5mm_P2.54mm_Vertical
R43, R45: 47k; R_Axial_DIN0207_L6.3mm_D2.5mm_P2.54mm_Vertical
R44, R46: 1k; R_Axial_DIN0207_L6.3mm_D2.5mm_P2.54mm_Vertical
RV1, RV2, RV3: 100k; Potentiometer_Alps_RK097_Single_Horizontal
RV4: 100k; Potentiometer_Alps_RK097_Dual_Horizontal
U1, U2, U3, U4, U5, U6: TL074; DIP-14_W7.62mm
U7: LM13700; DIP-16_W7.62mm

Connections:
BODYF: R50.1, U5.8, U5.9
BP: R41.1, R45.1, U5.1, U5.2, U5.10
CV: R32.1, U2.13, U2.14
ECTL: R31.2, RV4.3, U4.1
FZ: C10.1, C13.1, R13.2, R36.1
FZ1: C5.2, C6.1, D2.1, D3.2, R6.2, U1.8
FZ2: C7.2, C8.1, D5.1, D6.2, R9.2, U1.14
FZ3: C9.2, D8.1, D9.2, R12.2, R13.1, U2.1
GND: C1.2, C2.2, C19.2, C20.2, C21.2, C22.2, C23.2, C24.2, C25.2, J1.S, J2.S, J3.1, R2.2, R29.2, U1.11, U2.11, U3.11, U4.11, U5.11, U6.11, U7.6, U7.7, U7.10
HP: R40.2, R43.1, U4.14
LP: R39.1, U5.6, U5.7
unnamed: C4.2, R4.1, R5.1
unnamed: R5.2, RV2.1
unnamed: C5.1, D2.2, D4.1, R6.1, RV2.2, RV2.3, U1.9
unnamed: D3.1, D4.2
unnamed: C6.2, R7.1, R8.1
unnamed: C7.1, D5.2, D7.1, R8.2, R9.1, U1.13
unnamed: D6.1, D7.2
unnamed: C8.2, R10.1, R11.1
unnamed: C9.1, D8.2, D10.1, R11.2, R12.1, U2.2
unnamed: D9.1, D10.2
unnamed: D11.1, R14.2, R15.1, U2.6
unnamed: R16.2, R17.2, R18.1, U2.9
unnamed: D12.2, R15.2, R17.1
unnamed: D11.2, D12.1, U2.7
unnamed: C11.1, R19.2, R20.1
unnamed: C12.1, R20.2, U2.12
unnamed: C13.2, R21.1, R23.1
unnamed: R25.2, R26.1, U3.7
unnamed: D13.1, R21.2, R22.1, U3.2
unnamed: R23.2, R24.2, R25.1, U3.6
unnamed: D14.2, R22.2, R24.1
unnamed: D13.2, D14.1, U3.1
unnamed: C14.1, C15.1, R26.2
unnamed: C15.2, R27.1, U3.10
unnamed: R28.2, R29.1, U3.12
unnamed: R30.2, R31.1, U4.2
unnamed: R32.2, R33.1, U4.3
unnamed: R34.2, U7.1
unnamed: R35.2, U7.16
unnamed: R37.2, R38.1, U4.8
unnamed: R36.2, R37.1, U4.9
unnamed: R38.2, R39.2, R40.1, R42.2, RV4.5, U4.13
unnamed: R41.2, R42.1, RV4.4, RV4.6
unnamed: R43.2, R44.1, U7.3
unnamed: C16.1, U5.3, U7.5
unnamed: R45.2, R46.1, U7.14
unnamed: C17.1, U5.5, U7.12
unnamed: R47.1, RV3.1, U5.14
unnamed: R47.2, R48.1, U5.13
unnamed: C18.1, RV3.2
unnamed: C18.2, R49.1, U6.3
unnamed: R50.2, R51.2, R52.1, U6.6
unnamed: RV1.2, U6.10
unnamed: U6.13, U6.14
NP: C3.2, R3.1, U1.5
NREF: C2.1, R1.2, R2.1, U1.3
OCTF: R51.1, U6.1, U6.2
OCTV: U3.8, U3.9, U5.12
OPRE: R52.2, RV1.1, U6.7
OUT: J2.T, U6.8, U6.9
RABS_E: R18.2, R19.1, U2.8
SIG: C4.1, R14.1, R16.1, U1.6, U1.7
SIN: C3.1, J1.T
VBIAS: R34.1, R35.1, U4.6, U4.7
VBP: RV4.2, U4.5
VCC: C1.1, C19.1, C20.1, C21.1, C22.1, C23.1, C24.1, C25.1, D1.1, R1.1, R28.1, U1.4, U2.4, U3.4, U4.4, U5.4, U6.4, U7.11
VOFF: R33.2, RV4.1, U3.13, U3.14
VRAW: D1.2, J3.2
VREF: C10.2, C11.2, C12.2, C14.2, C16.2, C17.2, R3.2, R4.2, R7.2, R10.2, R27.2, R30.1, R44.2, R46.2, R48.2, R49.2, RV1.3, RV3.3, U1.1, U1.2, U1.10, U1.12, U2.3, U2.5, U2.10, U3.3, U3.5, U4.10, U4.12, U6.5, U6.12, U7.4, U7.13

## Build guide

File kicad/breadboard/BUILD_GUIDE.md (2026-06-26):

# Angry Squealing Duck — breadboard build guide

Prototype the pedal on solderless breadboards **one stage at a time**, testing each before
moving on, so a problem is caught in a 5-part block instead of a 100-part haystack. The
circuit is identical to the PCB; only the physical build differs.

- **Wiring detail:** [`CONNECTIONS.md`](CONNECTIONS.md) — per stage, every net is one
  breadboard row; put the listed pins in that row. IC pins are annotated (e.g. `U1.2 (IN1-)`).
- **Drawn schematics** (the simple stages SKiDL could auto-draw): `01_supply.png`,
  `02_input_buffer.png`, `05_envelope.png`, `06_quack_vtoi.png`. The dense stages (fuzz,
  octave, filter) are table-only — SKiDL's schematic auto-router can't handle them; the
  validated topology lives in `spice/blocks/*.cir` and the tables are generated from it.
- **Reference sound:** `audio/out/build_grid/` has the real-parts renders at every
  Squeal/Anger/Quack = 0/0.5/1.0 — listen to know what each stage *should* do.

> Op-amps here are allocated **per stage** (a fresh TL072/TL074 per block) — NOT the PCB's
> tight 6×TL074 packing — so each stage is independent and testable on its own.

## What you need
- Breadboards: 3–4 full-size (this is a big circuit).
- ICs: TL072 (DIP-8) and TL074 (DIP-14) op-amps, **1× LM13700** (DIP-16, the filter).
- 1N4148 diodes (~13), resistors + caps per `CONNECTIONS.md` (film for signal, electrolytic
  for the big supply/envelope caps), 4 pots (100k): **Volume, Anger, Squeal, Quack**.
- **9 V supply** (battery or regulated adapter), a DMM, and ideally a scope or an amp to listen.
- **One 0.1 µF ceramic from each IC's V+ pin to GND**, right at the chip (breadboard
  decoupling — skip it and the high-gain fuzz/filter may oscillate).

## Power & ground (build this rail discipline first)
- **VCC = +9 V**, **GND = 0 V** rails down both sides of every breadboard, linked together.
- **VREF = +4.5 V** is the "virtual ground" the whole pedal biases around — it is built by
  **Stage 1** and then distributed as a third rail to every other stage. Nearly every stage
  references VREF; run a wire for it everywhere.
- All inter-stage audio is AC-coupled and rides on VREF.

## The two pot wrinkles
- **Quack is a DUAL-GANG pot** (one knob, two ganged 100 k sections): section **A** lives in
  Stage 6 (the V-to-I "sweep" crossfade), section **B** lives in Stage 7 (the filter "Q").
  Use a real dual-gang 100 k pot (6 lugs), **or** two separate 100 k pots you turn together
  while testing.
- **Skip the true-bypass footswitch** while prototyping — just wire the input jack tip → Stage 2
  input, and Stage 8 output → output jack tip. Add switching later on the PCB.

## Inter-stage wiring (the wires between breadboard sections)
```
        IN ─► [2 Input buf] ─SIG─┬─► [3 Fuzz/Anger] ─FZ─┬─► [4 Octave/Squeal] ─OCTF─┐
                                 │                       └─► [7 Filter] ─BODYF───────┤
                                 └─► [5 Envelope] ─CV─► [6 V-to-I] ─VBIAS─► [7 Filter bias]
        [8 Output mix + Volume] ◄── BODYF + OCTF ──►  OUT ─► output jack
```
- **SIG** fans out to BOTH the fuzz (audio) and the envelope follower (control).
- **FZ** (fuzz output) fans out to BOTH the octave and the filter.
- **VBIAS** from Stage 6 biases the LM13700 in Stage 7 (this is what makes it quack).
- **BODYF** (filter) + **OCTF** (octave) meet at the Stage 8 mixer.

---

## Staged bring-up (build + test in this order)

### 1 — Supply / 4.5 V Vref   (table: `CONNECTIONS.md` §supply · schematic `01_supply.png`)
Build the reverse-protection diode, the 100 µF bulk cap, the 100k/100k divider + 47 µF, and
the TL072 buffer. **Test:** DMM — VCC = 9 V, **VREF = 4.5 V** (within ~0.1 V). Nothing else
works until this is solid.

### 2 — Input buffer   (§input_buffer · `02_input_buffer.png`)
Cin (100 n) + Rin (1 M to VREF) + unity buffer. **Test:** inject a signal (or plug a guitar)
at IN; on a scope, **SIG** is the same signal now centered on 4.5 V. Unity gain, no distortion.

### 3 — Fuzz (Anger)   (§fuzz_anger — table only, dense 3-stage Muff)
Three cascaded soft-clip stages (each: AC-couple, 1 M bias, gain op-amp, 100k/68k feedback +
1.5 n, asymmetric 1N4148 clippers), then a 2.2k/27n output low-pass → **FZ**. Anger (RV1) sets
stage-1 gain. **Test:** temporarily route SIG→FZ→an amp. Thick sustaining fuzz; Anger CCW =
cleaner/shorter, CW = maximum fuzz/sustain. If it squeals/oscillates, add the 0.1 µF decoupling.

### 4 — Octave (Squeal)   (§octave_squeal — table only)
HP into a precision full-wave rectifier (frequency doubler), gentle LP, AC-couple, ×8 makeup,
Squeal level pot, fixed ~330 Hz HP → **OCTF**. **Test:** FZ→octave→amp; you'll hear the
up-octave "ring" over the fuzz. Squeal CCW = none, noon = ring on top, CW = octave-dominant
blast. Most obvious on single notes / upper frets.

### 5 — Envelope follower   (§envelope · `05_envelope.png`)
Full-wave rectifier + 2-pole averaging + buffer → **CV**. This is a *control* voltage, not
audio. **Test:** DMM/scope on CV — sits at 4.5 V when quiet, **rises above 4.5 V when you
play** and tracks your picking dynamics (the rise is small, tens of mV — that's expected and
why Stage 6 has high gain).

### 6 — Quack control / V-to-I   (§quack_vtoi · `06_quack_vtoi.png`)
Vpark divider + buffer, a ×73 difference amp (1.5k/110k — high gain because CV is tiny), the
Quack-**sweep** crossfade pot (gang A), and a buffer → **VBIAS**. **Test:** DMM on VBIAS —
~1.6 V parked, climbing toward several volts on hard attacks. Quack-sweep CCW = VBIAS stays
parked (no sweep); CW = full swing.

### 7 — LM13700 band-pass filter (Quack)   (§filter_lm13700 — table only)
The heart of the quack: op-amp inverter + summer feeding two LM13700 OTA-C integrators; **VBIAS
sets the cutoff** (via the 10k bias resistors into pins 1 & 16). Quack-**Q** pot (gang B) sets
resonance. Input = FZ, output = **BODYF**. **Test:** FZ→filter→amp with VBIAS connected — the
body now *quacks*: bright on the pick attack, darkening as the note decays. Quack-Q CCW = gentle,
CW = vocal/resonant. **Quack is most audible with Squeal low** (at full Squeal the octave sits on top).

### 8 — Output (mix + Volume)   (§output — table only)
Op-amp mixer sums **BODYF + OCTF** (22k each), then a Volume pot + buffer → **OUT** → output
jack. **Test:** the whole pedal. Volume sets level; compare against `audio/out/build_grid/`.

---

### Once it all works
Wire SIG→(fuzz + envelope), FZ→(octave + filter), VBIAS→filter, BODYF+OCTF→output. Sweep all
four knobs and A/B against the grid renders. Then graduate to the PCB (`kicad/duck.kicad_pcb`)
— same circuit, soldered.

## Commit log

2026-06-25 second attempt at pedal circuit
2026-06-26 kicad pcb design is done
    [duck-B_Courtyard.gbr, duck-B_Cu.gbl, duck-B_Fab.gbr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]
2026-06-26 board updated with improved quack
    [duck-B_Courtyard.gbr, duck-B_Cu.gbl, duck-B_Fab.gbr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]
2026-06-26 added breadboard instructions
    [01_supply.kicad_sch, 02_input_buffer.kicad_sch, 05_envelope.kicad_sch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]
2026-06-26 audited and correct pcb design, updated breadboard instructions
    [duck-B_Courtyard.gbr, duck-B_Cu.gbl, duck-B_Fab.gbr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]
